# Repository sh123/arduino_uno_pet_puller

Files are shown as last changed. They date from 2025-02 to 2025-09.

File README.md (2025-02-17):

# Arduino plastic bottle to PET filament puller
This project is Arduino UNO/Duemilanove shield and minimalistic firmware for "Petalot PET Bottle to 3D filament" or another device with similar mechanics.

For more information about Petalot and its construction read at https://github.com/function3d/petalot.

This alternative board version based on parts and components found in a junk box, such as old Arduino UNO/Duemilanove, MX1508 stepper controller, external 12-13V power suppply, EM257 stepper from old printer, unlike origintal version it does not use WiFi remote control.

NB! PCB board is designed to be suitable for CNC milling, so some layout design decisions might look somewhat illogical.

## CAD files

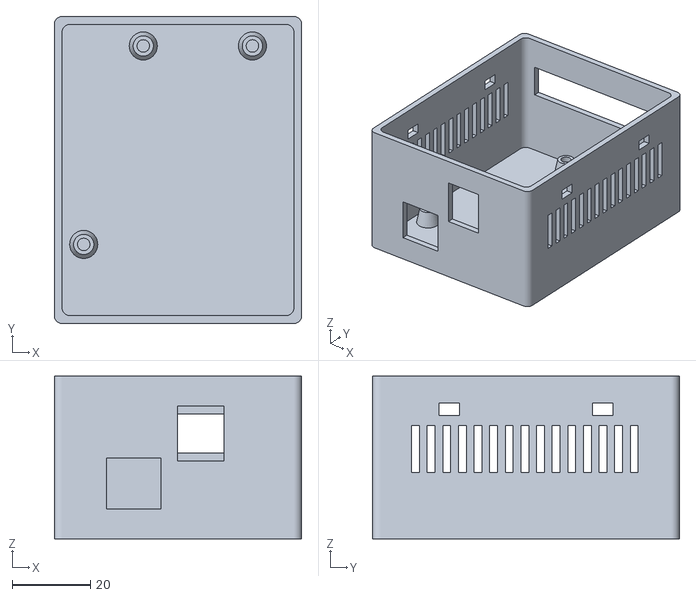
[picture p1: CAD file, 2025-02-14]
extras/cad/box.stl
63.3 x 78.6 x 41.7

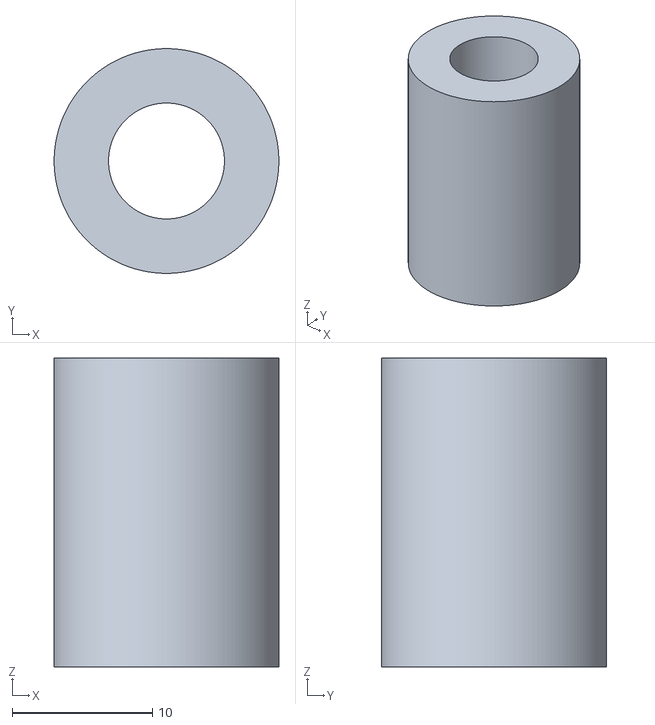
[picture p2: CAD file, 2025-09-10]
extras/cad_petalot/spacer-22.stl
16.0 x 16.0 x 22.0

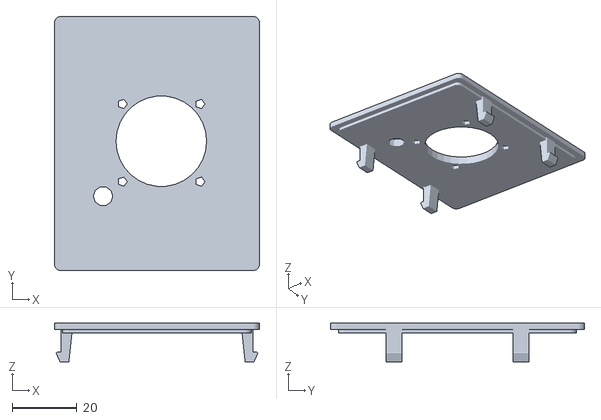
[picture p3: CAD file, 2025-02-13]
extras/cad/lid.stl
63.3 x 78.6 x 12.0

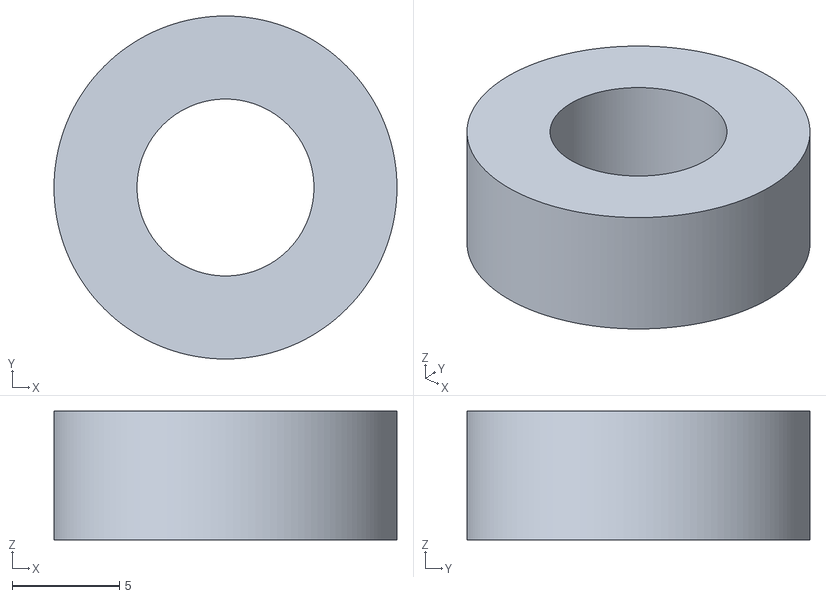
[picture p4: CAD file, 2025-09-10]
extras/cad_petalot/spacer-6.stl
16.0 x 16.0 x 6.00

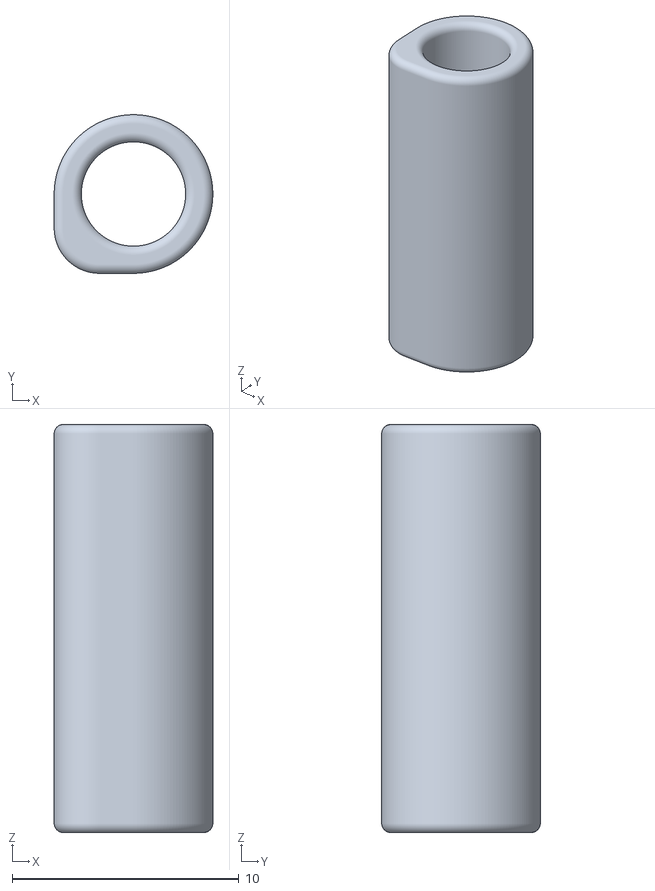
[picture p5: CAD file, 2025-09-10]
extras/cad_petalot/filament-hook.stl
7.00 x 7.00 x 18.0

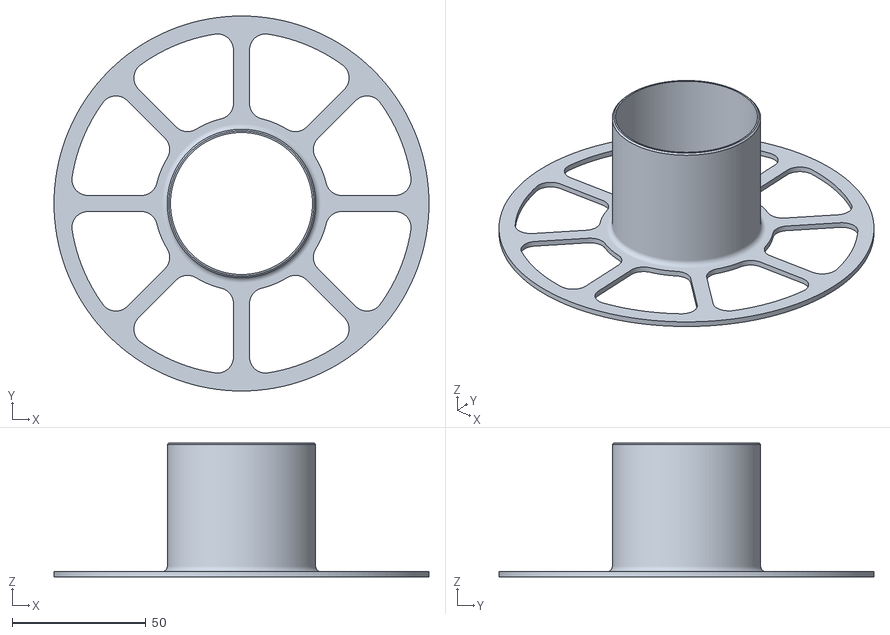
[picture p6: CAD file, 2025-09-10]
extras/cad_petalot/spool-14cm-part-1.stl
140.0 x 140.0 x 50.0

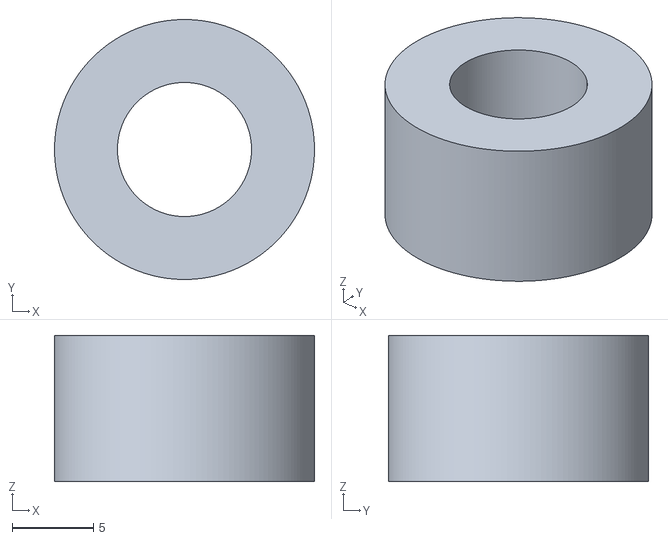
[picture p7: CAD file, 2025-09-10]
extras/cad_petalot/spacer-9.stl
16.0 x 16.0 x 9.00

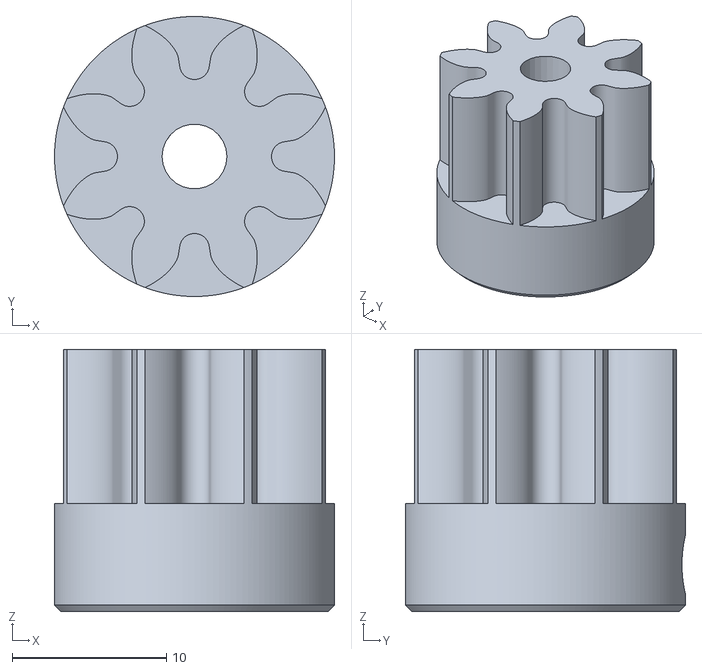
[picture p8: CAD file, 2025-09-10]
extras/cad_petalot/gear-motor_4mm.stl
18.1 x 18.1 x 17.0

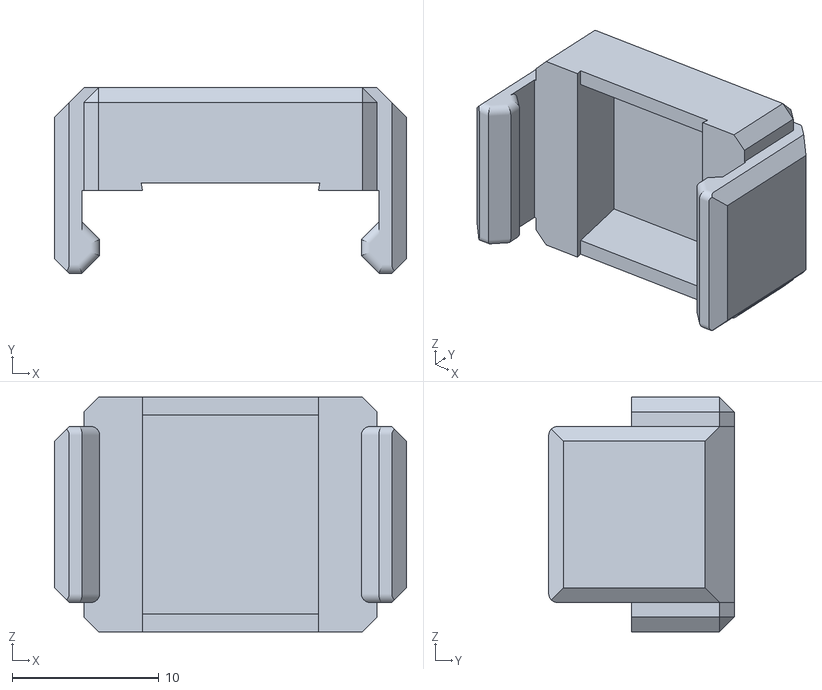
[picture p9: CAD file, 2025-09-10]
extras/cad_petalot/guide-cap-supports-touching-the-build-plate.stl
24.0 x 12.7 x 16.0

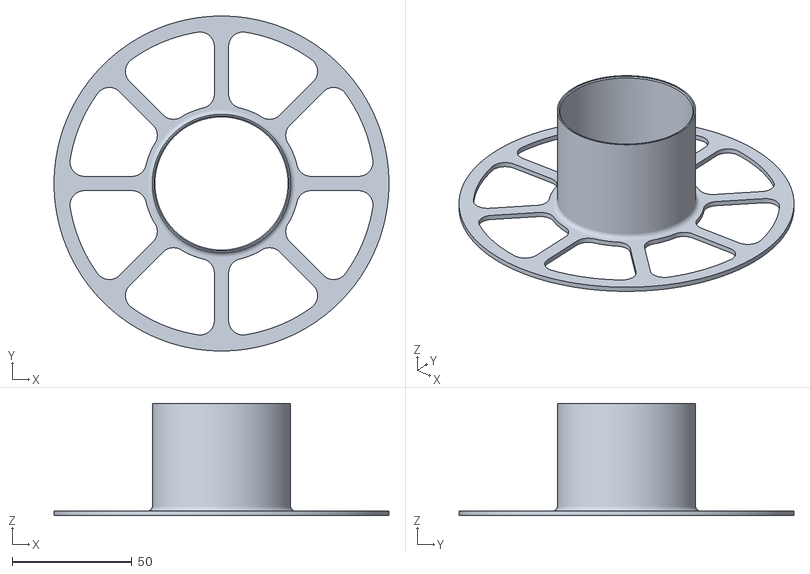
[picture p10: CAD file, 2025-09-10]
extras/cad_petalot/spool-14cm-part-2.stl
140.0 x 140.0 x 47.0

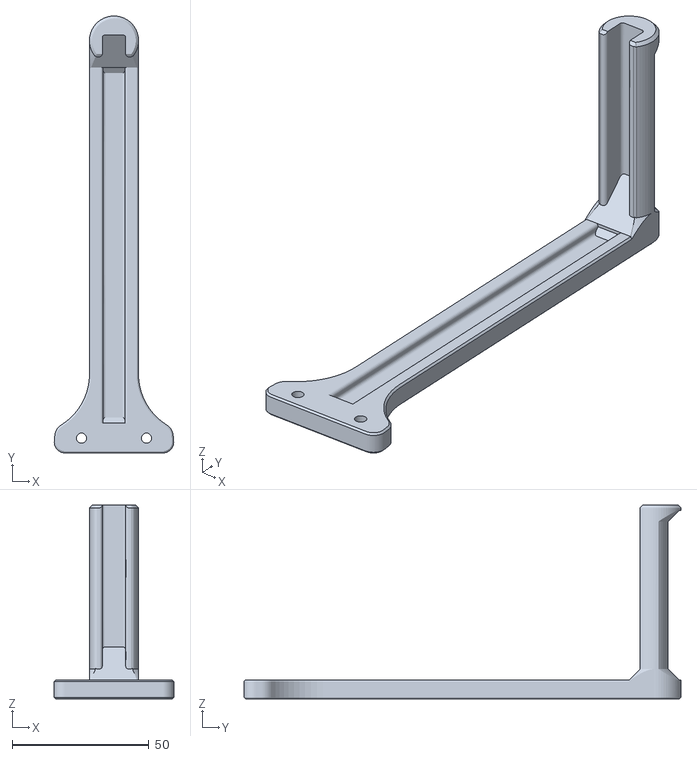
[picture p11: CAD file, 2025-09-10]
extras/cad_petalot/spool-holder.stl
43.8 x 160.0 x 71.0

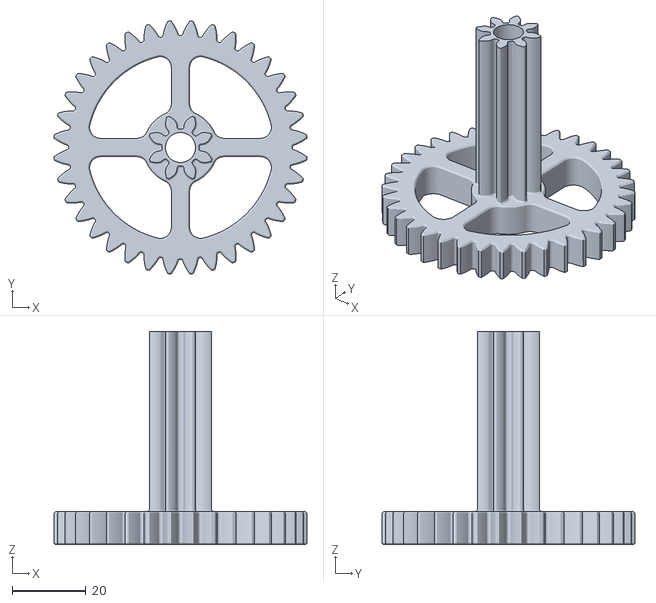
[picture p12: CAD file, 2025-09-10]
extras/cad_petalot/gear-mid.stl
68.8 x 68.8 x 58.0

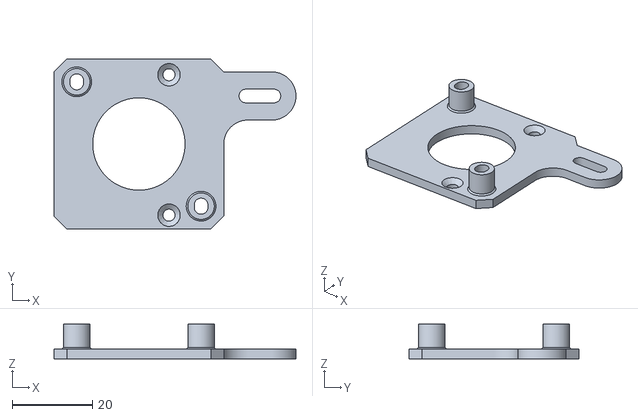
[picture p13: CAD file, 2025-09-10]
extras/cad_petalot/motor-spacer-28byj.stl
60.3 x 42.3 x 8.70

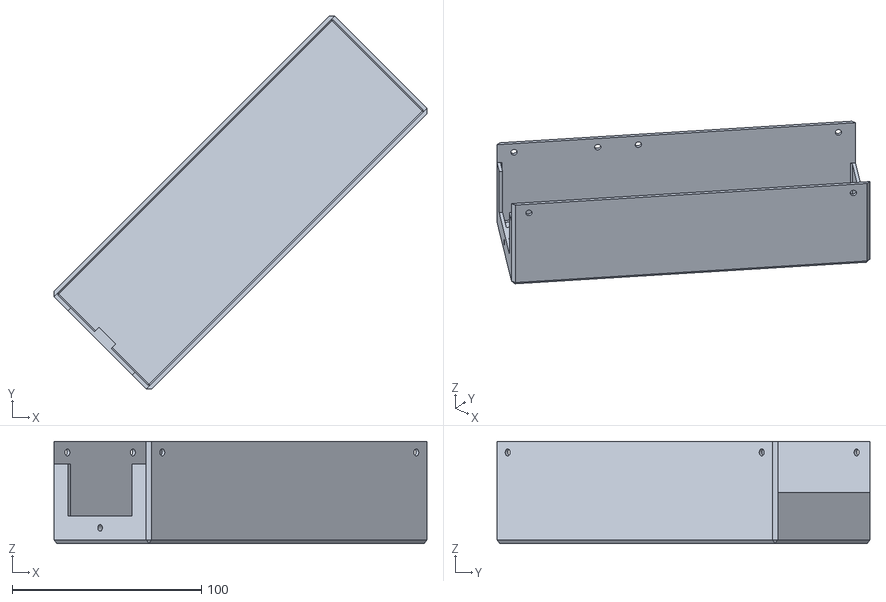
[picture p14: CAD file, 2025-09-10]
extras/cad_petalot/electronic-box.stl
197.3 x 197.3 x 54.0

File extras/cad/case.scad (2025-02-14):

include <OpenSCAD-Arduino-Mounting-Library/arduino.scad>

// type of board
cfg_board_type_ = DUEMILANOVE;       // [DUEMILANOVE, UNO]

// element to generate
cfg_generate_element_ = "box";       // [box, lid]

// include arduino board
cfg_include_board_ = "no";           // [yes, no]

// box additional height
cfg_additional_height_ = 22;

// wall width
cfg_wall_width_ = 2;

// space between board and wall
cfg_wall_board_space_ = 3;

if (cfg_generate_element_ == "box")
{
   box_generate(cfg_board_type_, cfg_include_board_, cfg_wall_width_, cfg_wall_board_space_, cfg_additional_height_);
}
else if (cfg_generate_element_ == "lid") 
{
    lid_generate(cfg_board_type_, cfg_wall_width_, cfg_wall_board_space_);
}
else
{
    echo("Unknown element", cfg_generate_element_);
}

// generate box
module box_generate(board_type, include_board, wall_width, wall_board_space, additional_height)
{
    // old power socket
    old_socket_x = 39;
    old_socket_y = -5;
    old_socket_z = 7;
    
    // vent holes
    vent_hole_count = 14;
    vent_hole_height = 12;
    vent_hole_width = 2;
    vent_hole_span = 75;
    vent_hole_x = -10;
    vent_hole_y = 5;
    vent_hole_z = 17;
    
    // cable hole
    cable_hole_width = 50;
    cable_hole_height = 10;
    cable_hole_x = 1;
    cable_hole_y = 70;
    cable_hole_z = 22;
    
    // power cable hole
    power_hole_width = 12;
    power_hole_height = 14;
    power_hole_x = 26.5;
    power_hole_y = -6;
    power_hole_z = 20;
    
    // common
    extrude_width = 14;
    
    difference() 
    {
        // case
        union()
        {
            if (include_board == "yes") 
            {
                translate([0, 0, 7])
                    arduino(board_type);
                        enclosure(board_type, wall_width, wall_board_space, additional_height);
            } else {
                enclosure(board_type, wall_width, wall_board_space, additional_height);
            }
            // close old power socket
            translate([old_socket_x, old_socket_y, old_socket_z])
                cube([power_hole_width, wall_width, power_hole_height]);
        } 
        // add vent holes
        for (vent_hole_num = [0:vent_hole_count])
        {
            translate([vent_hole_x, vent_hole_y + vent_hole_num * 4, vent_hole_z])
                cube([vent_hole_span, vent_hole_width, vent_hole_height]);
        }
        // cable hole
        translate([cable_hole_x, cable_hole_y, cable_hole_z])
            cube([cable_hole_width, extrude_width, cable_hole_height]);
        // connector hole
        translate([power_hole_x, power_hole_y, power_hole_z])
            cube([power_hole_width, extrude_width, power_hole_height]);
    }
}

// generates lid
module lid_generate(board_type, wall_width, wall_board_space) 
{
    // led
    led_hole_radius = 3;
    led_x = 10;
    led_y = 18;
    
    // fan
    fan_screw_radius = 1.5;
    fan_hole_radius = 14;
    fan_x = 28;
    fan_y = 35;
    
    // fan holes
    hole_base_x = 16;
    hole_base_y = 22.5;
    hole_distance = 24;
    
    // common
    cylinder_height = 10;
    z_position = -2;
    
    difference() 
    {
        // enclosure body
        enclosureLid(board_type, wall_width, wall_board_space);
        // fan hole
        translate([fan_x, fan_y, z_position])
            cylinder(cylinder_height, fan_hole_radius, fan_hole_radius);
        // screw holes for fan
        translate([hole_base_x + hole_distance, hole_base_y + hole_distance, z_position])
            cylinder(cylinder_height, fan_screw_radius, fan_screw_radius);
        translate([hole_base_x, hole_base_y + hole_distance, z_position])
            cylinder(cylinder_height, fan_screw_radius, fan_screw_radius);
        translate([hole_base_x + hole_distance, hole_base_y, z_position])
            cylinder(cylinder_height, fan_screw_radius, fan_screw_radius);
        translate([hole_base_x, hole_base_y, z_position])
            cylinder(cylinder_height, fan_screw_radius, fan_screw_radius);
        // led hole
        translate([led_x, led_y, z_position])
            cylinder(cylinder_height, led_hole_radius, led_hole_radius);
    }
}

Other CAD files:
extras/cad_petalot/motor-spacer.stl
extras/cad_petalot/guide-base.stl
extras/cad_petalot/gear-motor.stl
extras/cad_petalot/cable-clamp.stl
extras/cad_petalot/body-2.stl
extras/cad_petalot/electronic-box-washer-x4.stl
extras/cad_petalot/filament-sensor-body.stl
extras/cad_petalot/filament-sensor-cap.stl
extras/cad_petalot/motor-washer-x3.stl
extras/cad_petalot/pulley.stl
extras/cad_petalot/spacer-8.stl

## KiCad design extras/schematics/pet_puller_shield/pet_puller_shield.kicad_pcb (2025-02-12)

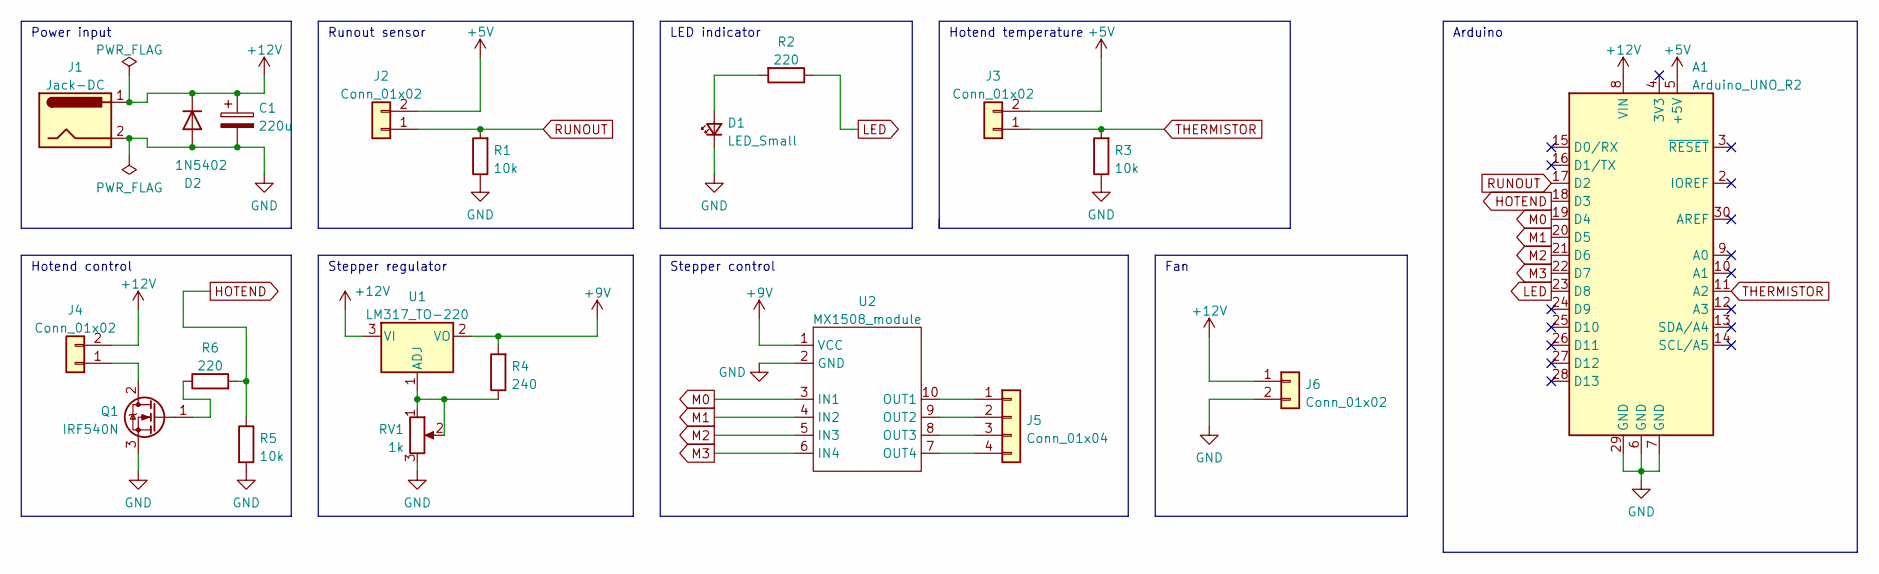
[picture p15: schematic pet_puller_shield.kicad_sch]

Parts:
A1: Arduino_UNO_R2
C1: 220u; CP_Radial_D8.0mm_P3.80mm
D1: LED_Small; LED_D3.0mm
D2: 1N5402; D_DO-201AD_P15.24mm_Horizontal
J1: Jack-DC; BarrelJack_GCT_DCJ200-10-A_Horizontal
J2, J3, J6: Conn_01x02; JST_EH_B2B-EH-A_1x02_P2.50mm_Vertical
J4: Conn_01x02; JST_NV_B02P-NV_1x02_P5.00mm_Vertical
J5: Conn_01x04; JST_EH_B4B-EH-A_1x04_P2.50mm_Vertical
Q1: IRF540N; TO-220-3_Horizontal_TabDown
R1, R3, R5: 10k; R_Axial_DIN0204_L3.6mm_D1.6mm_P5.08mm_Horizontal
R2, R6: 220; R_Axial_DIN0204_L3.6mm_D1.6mm_P5.08mm_Horizontal
R4: 240; R_Axial_DIN0204_L3.6mm_D1.6mm_P5.08mm_Horizontal
RV1: 1k; Potentiometer_Bourns_3339P_Vertical
U1: LM317_TO-220; TO-220-3_Horizontal_TabDown
U2: MX1508_module; mx1508_module

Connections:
+5V: A1.5 (+5V), J2.2, J3.2
+9V: R4.2, U1.2 (VO), U2.1 (VCC)
+12V: A1.8 (VIN), C1.1, D2.1 (K), J1.1, J4.2, J6.1, U1.3 (VI)
GND: A1.6 (GND), A1.7 (GND), A1.29 (GND), C1.2, D1.1 (K), D2.2 (A), J1.2, J1.3, J6.2, Q1.3 (S), R1.1, R3.1, R5.2, RV1.3, U2.2 (GND)
HOTEND: A1.18 (D3), R5.1, R6.2
LED: A1.23 (D8), R2.1
M0: A1.19 (D4), U2.3 (IN1)
M1: A1.20 (D5), U2.4 (IN2)
M2: A1.21 (D6), U2.5 (IN3)
M3: A1.22 (D7), U2.6 (IN4)
unnamed: D1.2 (A), R2.2
unnamed: J4.1, Q1.2 (D)
unnamed: J5.1, U2.10 (OUT1)
unnamed: J5.2, U2.9 (OUT2)
unnamed: J5.3, U2.8 (OUT3)
unnamed: J5.4, U2.7 (OUT4)
unnamed: Q1.1 (G), R6.1
unnamed: R4.1, RV1.1, RV1.2, U1.1 (ADJ)
RUNOUT: A1.17 (D2), J2.1, R1.2
THERMISTOR: A1.11 (A2), J3.1, R3.2

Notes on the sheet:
Fan
Stepper control
Arduino
Runout sensor
Power input
LED indicator
Hotend temperature
Hotend control
Stepper regulator

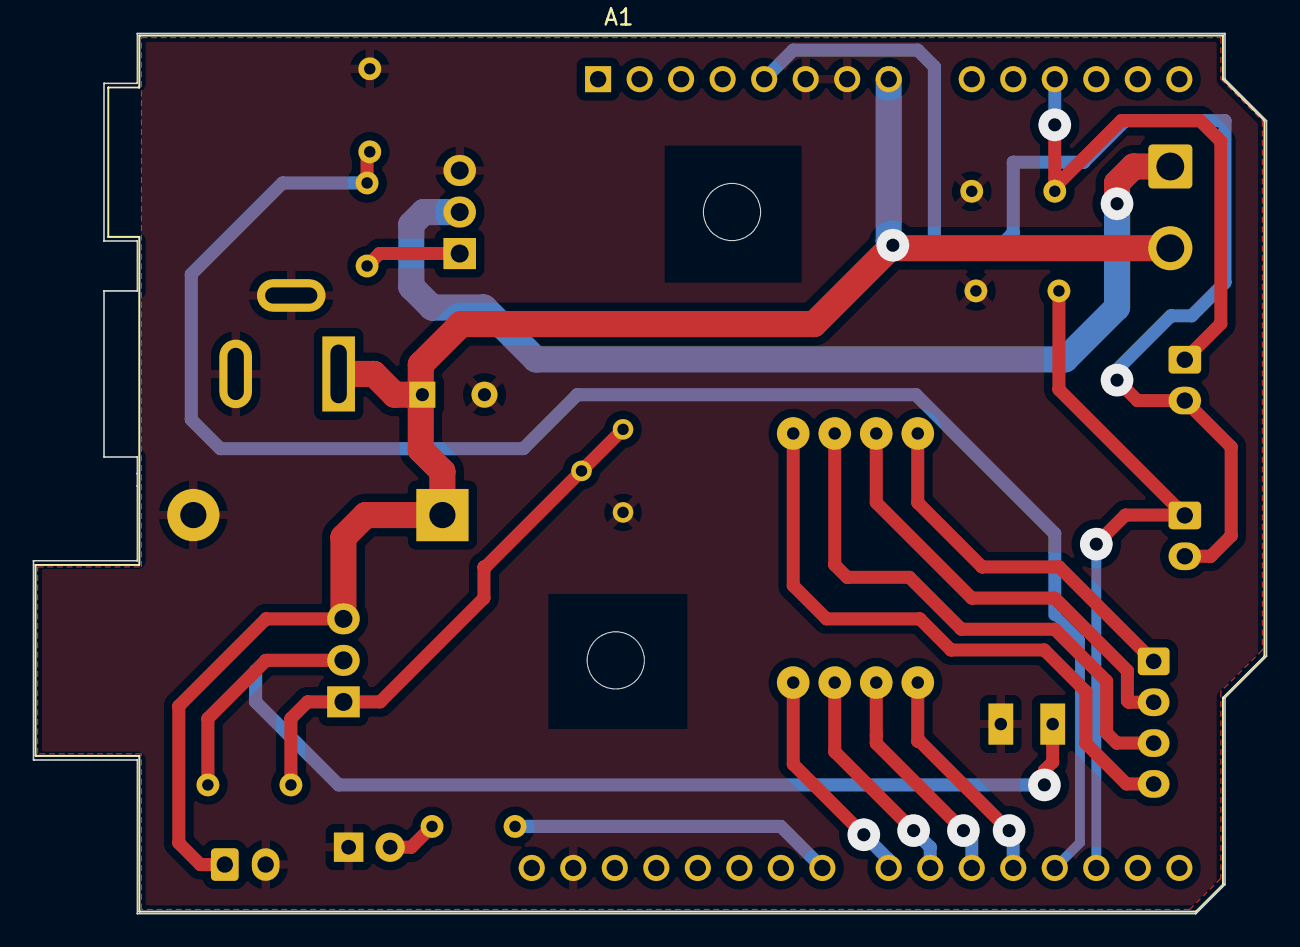
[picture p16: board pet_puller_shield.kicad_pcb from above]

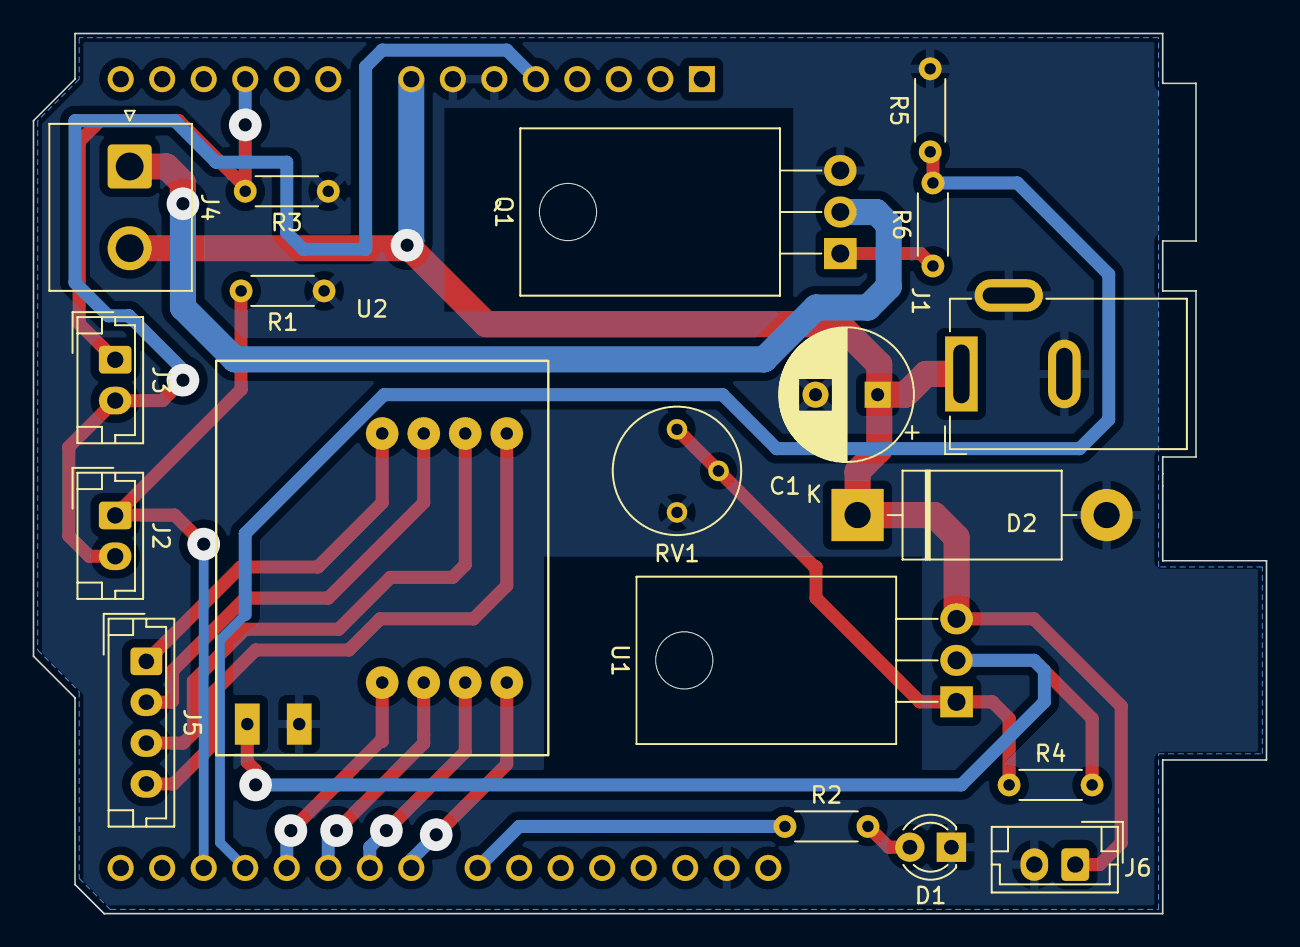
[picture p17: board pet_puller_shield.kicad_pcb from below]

Board: 2 copper layers, 75.4 x 53.8 mm, 20 parts (19 on the bottom side), 20 nets.

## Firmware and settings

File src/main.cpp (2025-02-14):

#include <Arduino.h>
#include <arduino-timer.h>
#include <Stepper.h>
#include <PID_v1.h>

#define CFG_TIMER_COUNT         3

#define CFG_STEPPER_RPM         40      // tune for desired feed speed
#define CFG_STEPPER_STEPS       200
#define CFG_STEPPER_STEP        1
#define CFG_STEPPER_RUN_MS      60L*1000L/CFG_STEPPER_STEPS/CFG_STEPPER_RPM     
#define CFG_STEPPER_PIN_M0      4
#define CFG_STEPPER_PIN_M1      5
#define CFG_STEPPER_PIN_M2      6
#define CFG_STEPPER_PIN_M3      7

#define CFG_LED_PIN             8
#define CFG_HOTEND_PIN          3
#define CFG_RUNOUT_PIN          2

#define CFG_THERMISTOR_PIN      A2
#define CFG_THERMISTOR_RUN_MS   2L*1000L
#define CFG_THERMISTOR_R        10000

#define CFG_PID_KP              23.0
#define CFG_PID_KI              0.043
#define CFG_PID_KD              160.0
#define CFG_PID_TEMP            200.0   // tune for desired temperature
#define CFG_PID_MAX_TEMP        240.0
#define CFG_PID_MAX_OUTPUT      200.0
#define CFG_PID_READY_TEMP      150.0

#define CFG_HOTEND_TIMEOUT_MS   5L*60L*1000L

volatile bool runoutHasFilament_=false, runoutTriggered_=false;
double pidInput_, pidOutput_, pidSetpoint_=CFG_PID_TEMP;
bool hotendIsPaused_ = true;

Timer<CFG_TIMER_COUNT, millis> timer_;
Timer<>::Task hotendPauseTask_;

Stepper stepper_(CFG_STEPPER_STEPS, CFG_STEPPER_PIN_M0, 
    CFG_STEPPER_PIN_M1, CFG_STEPPER_PIN_M2, CFG_STEPPER_PIN_M3);

PID pid_(&pidInput_, &pidOutput_, &pidSetpoint_, CFG_PID_KP, 
    CFG_PID_KI, CFG_PID_KD, DIRECT);

double thermistorRead() {
    static const double c1 = 0.8438162826e-03, c2 = 2.059601750e-04, c3 = 0.8615484887e-07;
    double level = (double)analogRead(CFG_THERMISTOR_PIN);
    double levelR = CFG_THERMISTOR_R * (1023.0 / level - 1.0);
    double levelLogR = log(levelR);
    double tempKelvin = (1.0 / (c1 + c2 * levelLogR + c3 * levelLogR * levelLogR * levelLogR)); 
    return tempKelvin - 273.15;
}

bool stepperStepTask(void *arg) {
    if (!runoutHasFilament_) return true;
    stepper_.step(CFG_STEPPER_STEP);
    return true;
}

void stepperInitialize() {
    stepper_.setSpeed(CFG_STEPPER_RPM);
    timer_.every(CFG_STEPPER_RUN_MS, stepperStepTask);
}

void stepperRelease() {
    digitalWrite(CFG_STEPPER_PIN_M0, LOW); 
    digitalWrite(CFG_STEPPER_PIN_M1, LOW); 
    digitalWrite(CFG_STEPPER_PIN_M2, LOW); 
    digitalWrite(CFG_STEPPER_PIN_M3, LOW); 
}

bool hotendPauseTask(void *arg) {
    hotendIsPaused_ = true;
    digitalWrite(CFG_LED_PIN, LOW);
    analogWrite(CFG_HOTEND_PIN, 0);
    return true;
}

void hotendCancelPauseTimer() {
    if (hotendPauseTask_ != nullptr) {
        timer_.cancel(hotendPauseTask_);
        hotendPauseTask_ = nullptr;
    }
    hotendIsPaused_ = false;
}

void hotendStartPauseTimer() {
    hotendCancelPauseTimer();
    hotendPauseTask_ = timer_.in(CFG_HOTEND_TIMEOUT_MS, hotendPauseTask);
}

void runoutProcess() {
    if (!runoutTriggered_) return;
    runoutTriggered_ = false;
    Serial.println(runoutHasFilament_ ? F("ON") : F("OFF"));
    if (runoutHasFilament_) {
        hotendCancelPauseTimer();
    } else {
        stepperRelease();
        hotendStartPauseTimer();
    }
}

void runoutTriggeredInterrupt() {
    bool hasFilament = digitalRead(CFG_RUNOUT_PIN);
    if (runoutHasFilament_ == hasFilament) return;
    runoutHasFilament_ = hasFilament;
    runoutTriggered_ = true;
}

void runoutInitialize() {
    runoutHasFilament_ = false;
    runoutTriggered_ = false;
    pinMode(CFG_RUNOUT_PIN, INPUT);
    attachInterrupt(digitalPinToInterrupt(CFG_RUNOUT_PIN), runoutTriggeredInterrupt, CHANGE);
}

bool hotendTask(void *arg) {
    if (hotendIsPaused_) return true;
    pidInput_ = thermistorRead();
    if (pidInput_ > CFG_PID_MAX_TEMP || isnan(pidInput_)) {
        pidOutput_ = 0;
    } else {
        pid_.Compute();
    }
    Serial.print(pidInput_); Serial.print(' '); Serial.println(pidOutput_);
    analogWrite(CFG_HOTEND_PIN, pidOutput_);
    if (pidInput_ > CFG_PID_READY_TEMP) {
        digitalWrite(CFG_LED_PIN, HIGH);
    } else {
        digitalWrite(CFG_LED_PIN, !digitalRead(CFG_LED_PIN));
    }
    return true;
}

void hotendInitialize() {
    hotendIsPaused_ = true;
    hotendPauseTask_ = nullptr;

    pinMode(CFG_LED_PIN, OUTPUT);
    digitalWrite(CFG_LED_PIN, LOW);

    pinMode(CFG_HOTEND_PIN, OUTPUT);
    analogWrite(CFG_HOTEND_PIN, 0);

    pid_.SetTunings(CFG_PID_KP, CFG_PID_KI, CFG_PID_KD);
    pid_.SetOutputLimits(0, CFG_PID_MAX_OUTPUT);
    pid_.SetMode(AUTOMATIC);

    timer_.every(CFG_THERMISTOR_RUN_MS, hotendTask);
}

void setup() {
    hotendInitialize();
    stepperInitialize();
    runoutInitialize();

    Serial.begin(115200);
    while (!Serial);

    Serial.println(F("Started"));
}

void loop() {
    runoutProcess();
    timer_.tick();
}

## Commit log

2025-02-07 Added schematics
    [pet_puller_shield.kicad_pcb, pet_puller_shield.kicad_sch]
2025-02-08 Update schematics
2025-02-08 Updated schematics
    [pet_puller_shield-B_Cu.gbr, pet_puller_shield-B_Mask.gbr, pet_puller_shield-B_Paste.gbr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]
2025-02-08 Add drill files
    [pet_puller_shield-NPTH.drl, pet_puller_shield-PTH.drl]
2025-02-08 Updated schematics and gcode
    [pet_puller_shield.kicad_pcb, pet_puller_shield.kicad_sch]
2025-02-12 Code update
    [pet_puller_shield.kicad_sch]
2025-02-14 Adjust temperature
2025-09-10 Added source stl models
    [body-2.stl, cable-clamp.stl, electronic-box-washer-x4.stl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]
